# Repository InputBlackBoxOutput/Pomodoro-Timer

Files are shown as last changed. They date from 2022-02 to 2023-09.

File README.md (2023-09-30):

# Pomodoro Timer

A Pomodoro timer helps you focus on a task for 25 minutes and then take a 5-minute break

## 5 steps of the Pomodoro technique
1. Choose a task
2. Set the timer for 25 minutes
3. Work on the task until the timer rings
4. Take a 5-minute break
5. Repeat steps 1-4 three more times

## 3D Render: PCB + Enclosure
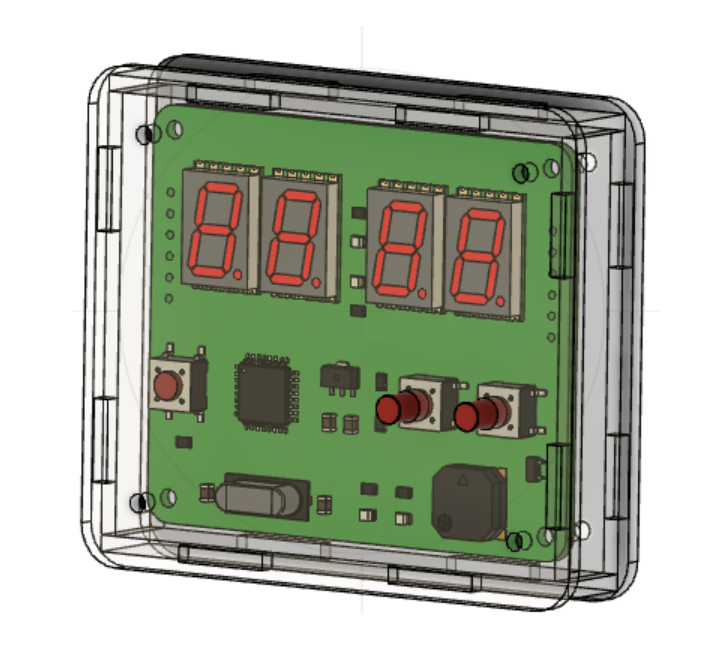
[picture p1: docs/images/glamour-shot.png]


## Hardware block diagram
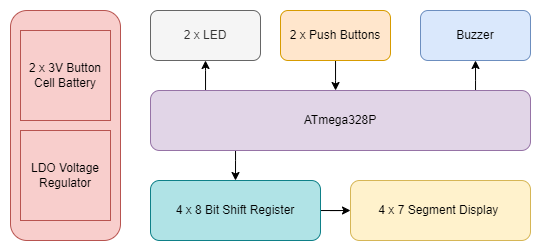
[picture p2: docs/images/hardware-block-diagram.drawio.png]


| Component | Function |
|--|--|
| ATmega328P | Micro-controller that controls all functionality |
| LED | Indicate the status of the Pomodoro timer |
| Push buttons | Provide an interface to start/stop and reset the Pomodoro timer |
| Buzzer | Provide auditory feedback upon completion of the timer |
| 4x7 segment display | Displays remaining time for the Pomodoro session |
| LDO voltage regulator | Efficiently regulates the voltage supplied to the embedded system |
| Cell battery | Provides power to the entire system |

### Made with lots of ⏱️, 📚 and ☕ by InputBlackBoxOutput

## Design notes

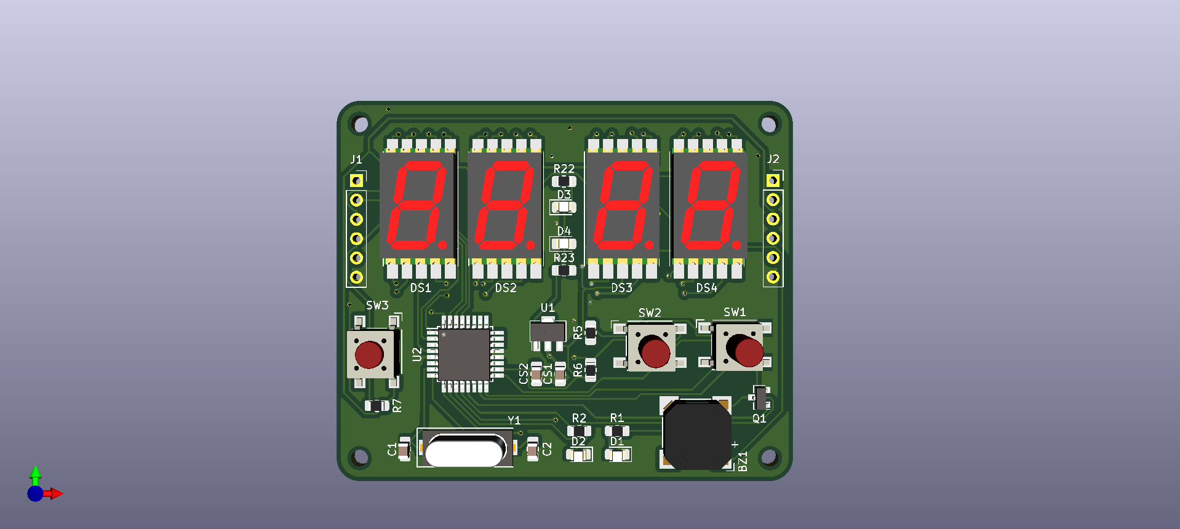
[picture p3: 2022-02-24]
docs/images/pcb-front.png

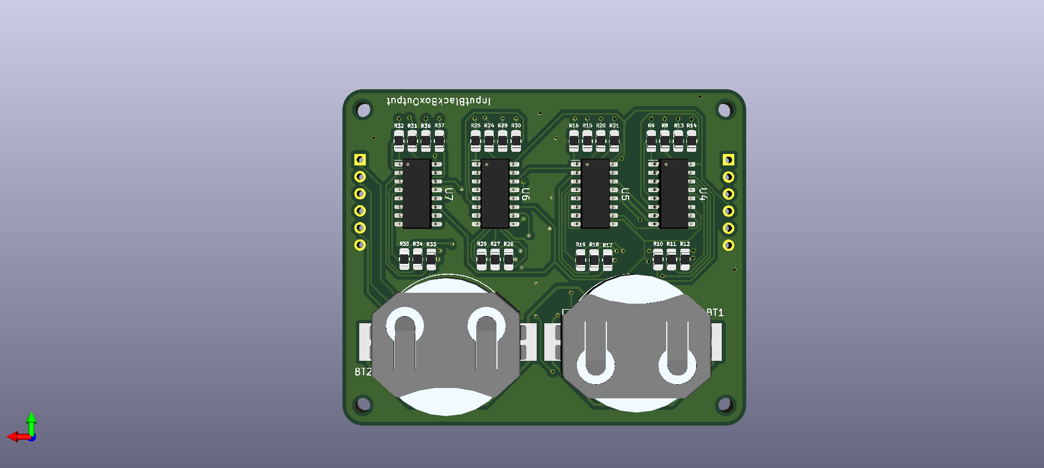
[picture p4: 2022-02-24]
docs/images/pcb-back.png

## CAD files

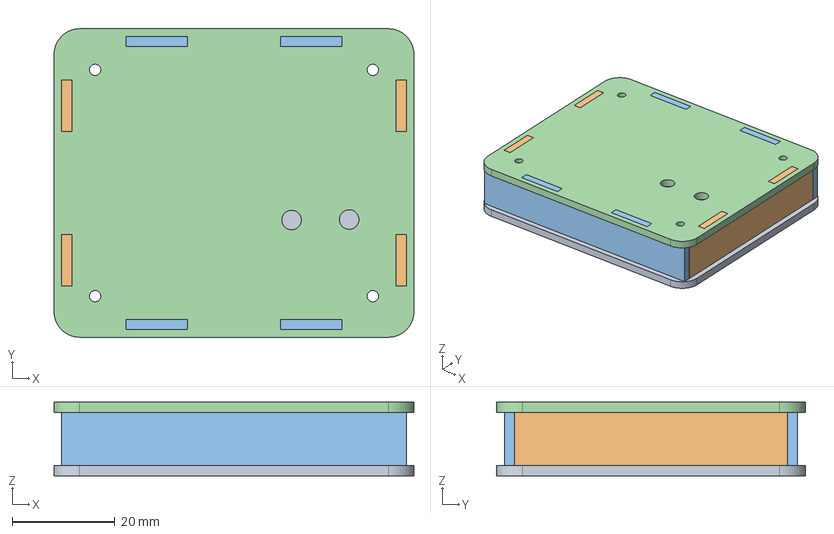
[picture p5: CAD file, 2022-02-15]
enclosure/enclosure.step
70.0 x 60.0 x 14.3 mm
Bottom
Left
Right
Front
Back
Top

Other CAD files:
enclosure/enclosure.dxf
enclosure/enclosure.f3d

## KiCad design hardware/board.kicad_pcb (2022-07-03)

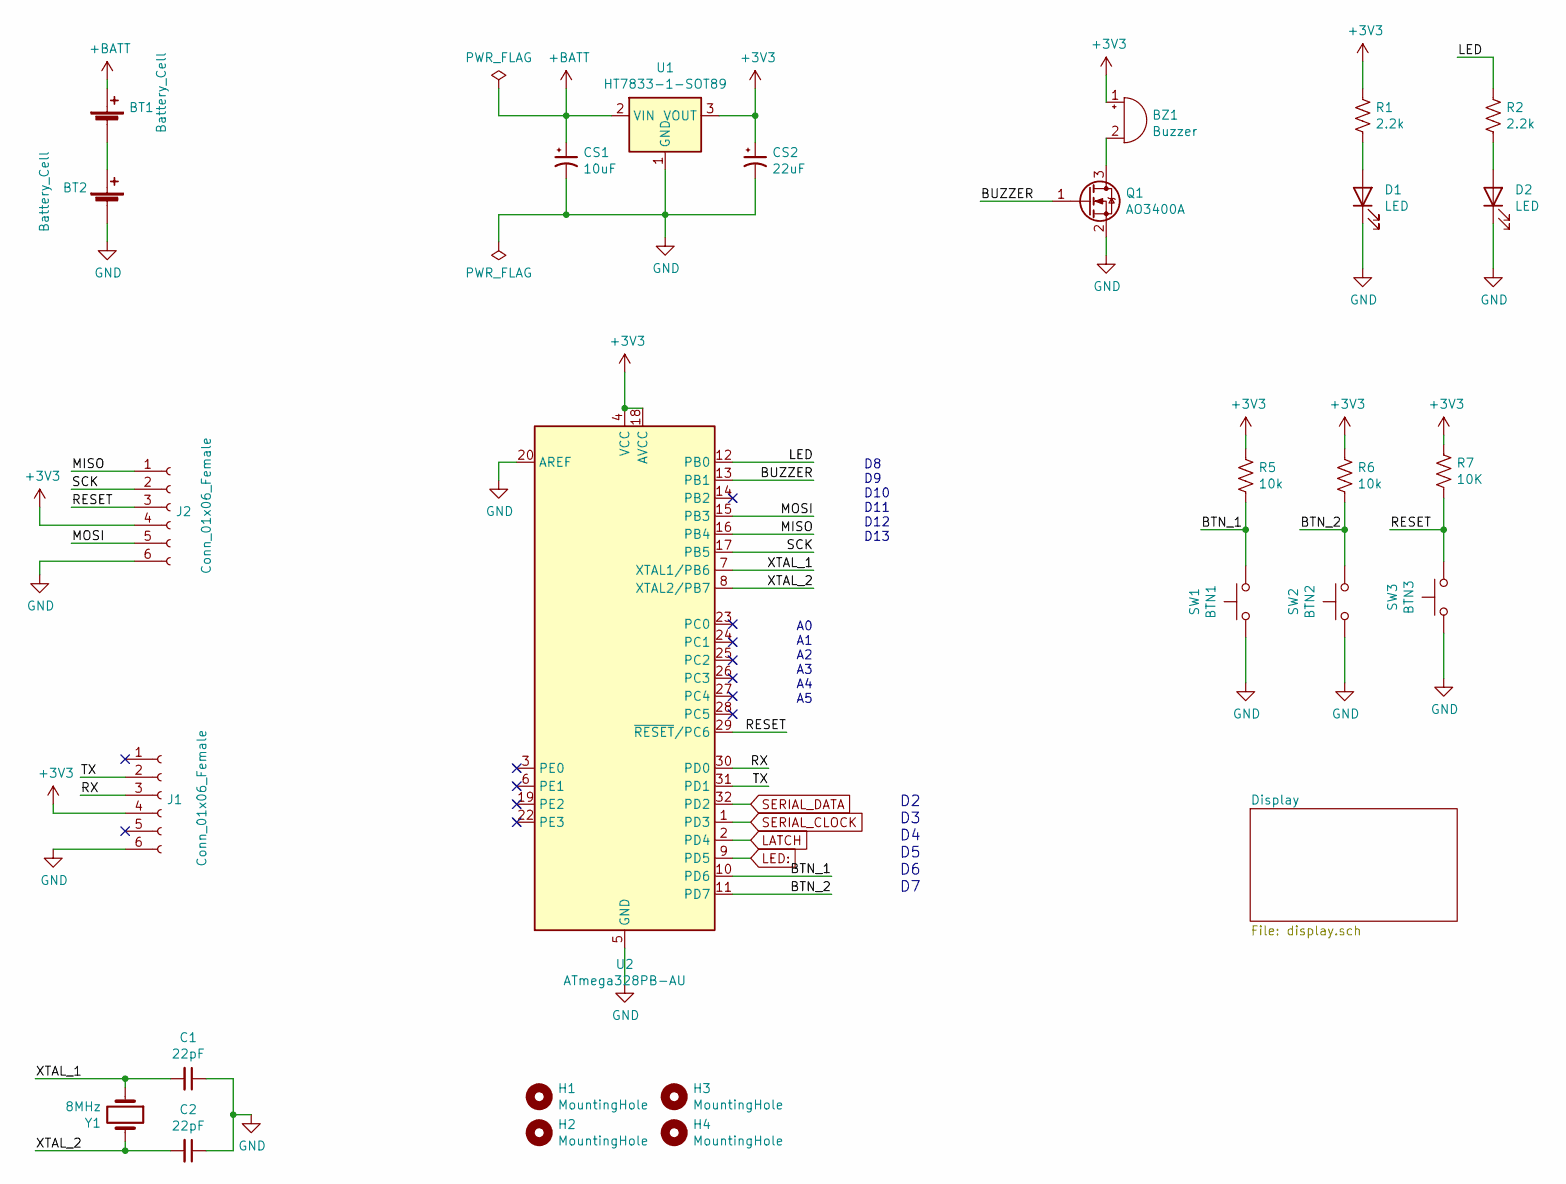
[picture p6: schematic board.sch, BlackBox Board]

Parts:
BT1, BT2: Battery_Cell; BatteryHolder_MPD_BC2003_1x2032
BZ1: Buzzer; MagneticBuzzer_CUI_CMT-8504-100-SMT
C1, C2: 22pF; C_0805_2012Metric_Pad1.18x1.45mm_HandSolder
CS1: 10uF; C_0805_2012Metric_Pad1.18x1.45mm_HandSolder
CS2: 22uF; C_0805_2012Metric_Pad1.18x1.45mm_HandSolder
D1, D2: LED; LED_0805_2012Metric_Pad1.15x1.40mm_HandSolder
H1, H2, H3, H4: MountingHole; MountingHole_2.2mm_M2
J1, J2: Conn_01x06_Female; PinSocket_1x06_P2.54mm_Vertical
Q1: AO3400A; SOT-23
R1, R2: 2.2k; R_0805_2012Metric_Pad1.20x1.40mm_HandSolder
R5, R6: 10k; R_0805_2012Metric_Pad1.20x1.40mm_HandSolder
R7: 10K; R_0805_2012Metric_Pad1.20x1.40mm_HandSolder
SW1: BTN1; SW_SPST_Omron_B3FS-100xP
SW2: BTN2; SW_SPST_Omron_B3FS-100xP
SW3: BTN3; SW_SPST_Omron_B3FS-100xP
U1: HT7833-1-SOT89; SOT-89-3
U2: ATmega328PB-AU; TQFP-32_7x7mm_P0.8mm
Y1: 8MHz; Crystal_SMD_HC49-SD

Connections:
+3V3: BZ1.1 (-), CS2.1, J1.4, J2.4, R1.1, R5.1, R6.1, R7.1, U1.3 (VOUT), U2.4 (VCC), U2.18 (AVCC); also elsewhere on the board
+BATT: BT1.1 (+), CS1.1, U1.2 (VIN)
/BTN_1: R5.2, SW1.2, U2.10 (PD6)
/BTN_2: R6.2, SW2.2, U2.11 (PD7)
/BUZZER: Q1.1 (G), U2.13 (PB1)
/LED: R2.1, U2.12 (PB0)
/MISO: J2.1, U2.16 (PB4)
/MOSI: J2.5, U2.15 (PB3)
/RESET: J2.3, R7.2, SW3.2, U2.29 (~RESET~/PC6)
/RX: J1.3, U2.30 (PD0)
/SCK: J2.2, U2.17 (PB5)
/TX: J1.2, U2.31 (PD1)
/XTAL_1: C1.2, U2.7 (XTAL1/PB6), Y1.1
/XTAL_2: C2.2, U2.8 (XTAL2/PB7), Y1.2
GND: BT2.2 (-), C1.1, C2.1, CS1.2, CS2.2, D1.1 (K), D2.1 (K), J1.6, J2.6, Q1.2 (S), SW1.1, SW2.1, SW3.1, U1.1 (GND), U2.5 (GND), U2.20 (AREF), U2.21 (GND); also elsewhere on the board
LATCH: U2.2 (PD4); also elsewhere on the board
LED:: U2.9 (PD5); also elsewhere on the board
unnamed: BT1.2 (-), BT2.1 (+)
unnamed: BZ1.2 (+), Q1.3 (D)
unnamed: D1.2 (A), R1.2
unnamed: D2.2 (A), R2.2
SERIAL_CLOCK: U2.1 (PD3); also elsewhere on the board
SERIAL_DATA: U2.32 (PD2); also elsewhere on the board

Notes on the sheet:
D2 D3 D4 D5 D6 D7
D8 D9 D10 D11 D12 D13
A0 A1 A2 A3 A4 A5

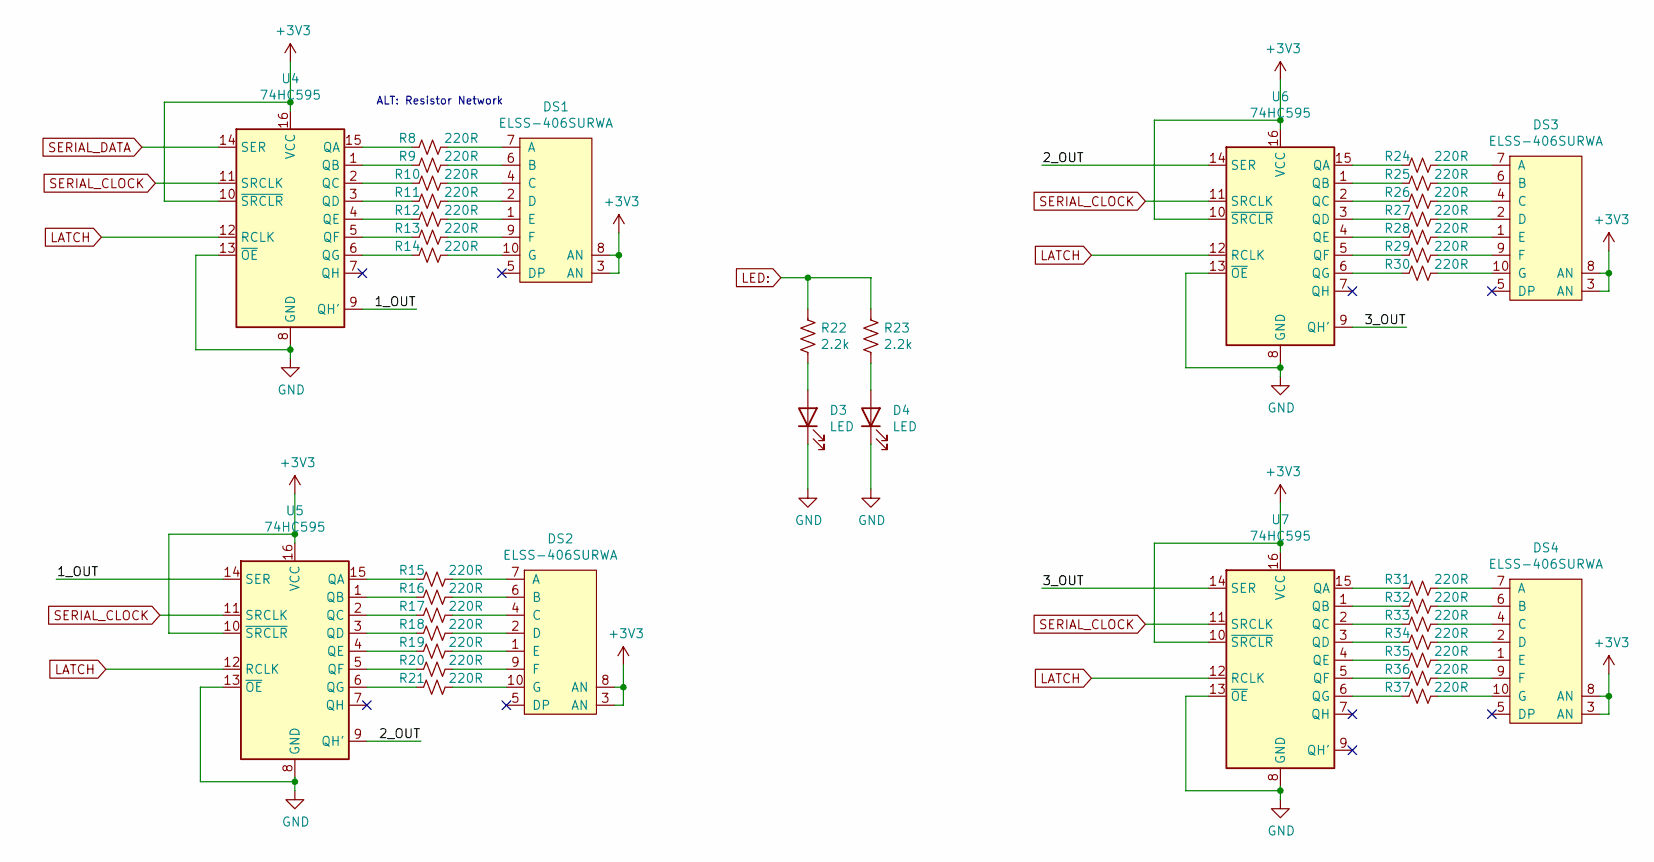
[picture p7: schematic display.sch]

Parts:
D3, D4: LED; LED_0805_2012Metric_Pad1.15x1.40mm_HandSolder
DS1, DS2, DS3, DS4: ELSS-406SURWA
R8, R9, R10, R11, R12, R13, R14, R15, R16, R17, R18, R19, R20, R21, R24, R25, R26, R27, R28, R29, R30, R31, R32, R33, R34, R35, R36, R37: 220R; R_0805_2012Metric_Pad1.20x1.40mm_HandSolder
R22, R23: 2.2k; R_0805_2012Metric_Pad1.20x1.40mm_HandSolder
U4, U5, U6, U7: 74HC595; SOP-16_3.9x9.9mm_P1.27mm

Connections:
+3V3: DS1.3 (AN), DS1.8 (AN), DS2.3 (AN), DS2.8 (AN), DS3.3 (AN), DS3.8 (AN), DS4.3 (AN), DS4.8 (AN), U4.10 (~SRCLR), U4.16 (VCC), U5.10 (~SRCLR), U5.16 (VCC), U6.10 (~SRCLR), U6.16 (VCC), U7.10 (~SRCLR), U7.16 (VCC); also elsewhere on the board
/Display/1_OUT: U4.9 (QH'), U5.14 (SER)
/Display/2_OUT: U5.9 (QH'), U6.14 (SER)
/Display/3_OUT: U6.9 (QH'), U7.14 (SER)
GND: D3.1 (K), D4.1 (K), U4.8 (GND), U4.13 (~OE), U5.8 (GND), U5.13 (~OE), U6.8 (GND), U6.13 (~OE), U7.8 (GND), U7.13 (~OE); also elsewhere on the board
LATCH: U4.12 (RCLK), U5.12 (RCLK), U6.12 (RCLK), U7.12 (RCLK); also elsewhere on the board
LED:: R22.1, R23.1; also elsewhere on the board
unnamed: D3.2 (A), R22.2
unnamed: D4.2 (A), R23.2
unnamed: DS1.1 (E), R12.1
unnamed: DS1.2 (D), R11.1
unnamed: DS1.4 (C), R10.1
unnamed: DS1.6 (B), R9.1
unnamed: DS1.7 (A), R8.1
unnamed: DS1.9 (F), R13.1
unnamed: DS1.10 (G), R14.1
unnamed: DS2.1 (E), R19.1
unnamed: DS2.2 (D), R18.1
unnamed: DS2.4 (C), R17.1
unnamed: DS2.6 (B), R16.1
unnamed: DS2.7 (A), R15.1
unnamed: DS2.9 (F), R20.1
unnamed: DS2.10 (G), R21.1
unnamed: DS3.1 (E), R28.1
unnamed: DS3.2 (D), R27.1
unnamed: DS3.4 (C), R26.1
unnamed: DS3.6 (B), R25.1
unnamed: DS3.7 (A), R24.1
unnamed: DS3.9 (F), R29.1
unnamed: DS3.10 (G), R30.1
unnamed: DS4.1 (E), R35.1
unnamed: DS4.2 (D), R34.1
unnamed: DS4.4 (C), R33.1
unnamed: DS4.6 (B), R32.1
unnamed: DS4.7 (A), R31.1
unnamed: DS4.9 (F), R36.1
unnamed: DS4.10 (G), R37.1
unnamed: R8.2, U4.15 (QA)
unnamed: R9.2, U4.1 (QB)
unnamed: R10.2, U4.2 (QC)
unnamed: R11.2, U4.3 (QD)
unnamed: R12.2, U4.4 (QE)
unnamed: R13.2, U4.5 (QF)
unnamed: R14.2, U4.6 (QG)
unnamed: R15.2, U5.15 (QA)
unnamed: R16.2, U5.1 (QB)
unnamed: R17.2, U5.2 (QC)
unnamed: R18.2, U5.3 (QD)
unnamed: R19.2, U5.4 (QE)
unnamed: R20.2, U5.5 (QF)
unnamed: R21.2, U5.6 (QG)
unnamed: R24.2, U6.15 (QA)
unnamed: R25.2, U6.1 (QB)
unnamed: R26.2, U6.2 (QC)
unnamed: R27.2, U6.3 (QD)
unnamed: R28.2, U6.4 (QE)
unnamed: R29.2, U6.5 (QF)
unnamed: R30.2, U6.6 (QG)
unnamed: R31.2, U7.15 (QA)
unnamed: R32.2, U7.1 (QB)
unnamed: R33.2, U7.2 (QC)
unnamed: R34.2, U7.3 (QD)
unnamed: R35.2, U7.4 (QE)
unnamed: R36.2, U7.5 (QF)
unnamed: R37.2, U7.6 (QG)
SERIAL_CLOCK: U4.11 (SRCLK), U5.11 (SRCLK), U6.11 (SRCLK), U7.11 (SRCLK); also elsewhere on the board
SERIAL_DATA: U4.14 (SER); also elsewhere on the board

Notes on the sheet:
ALT: Resistor Network

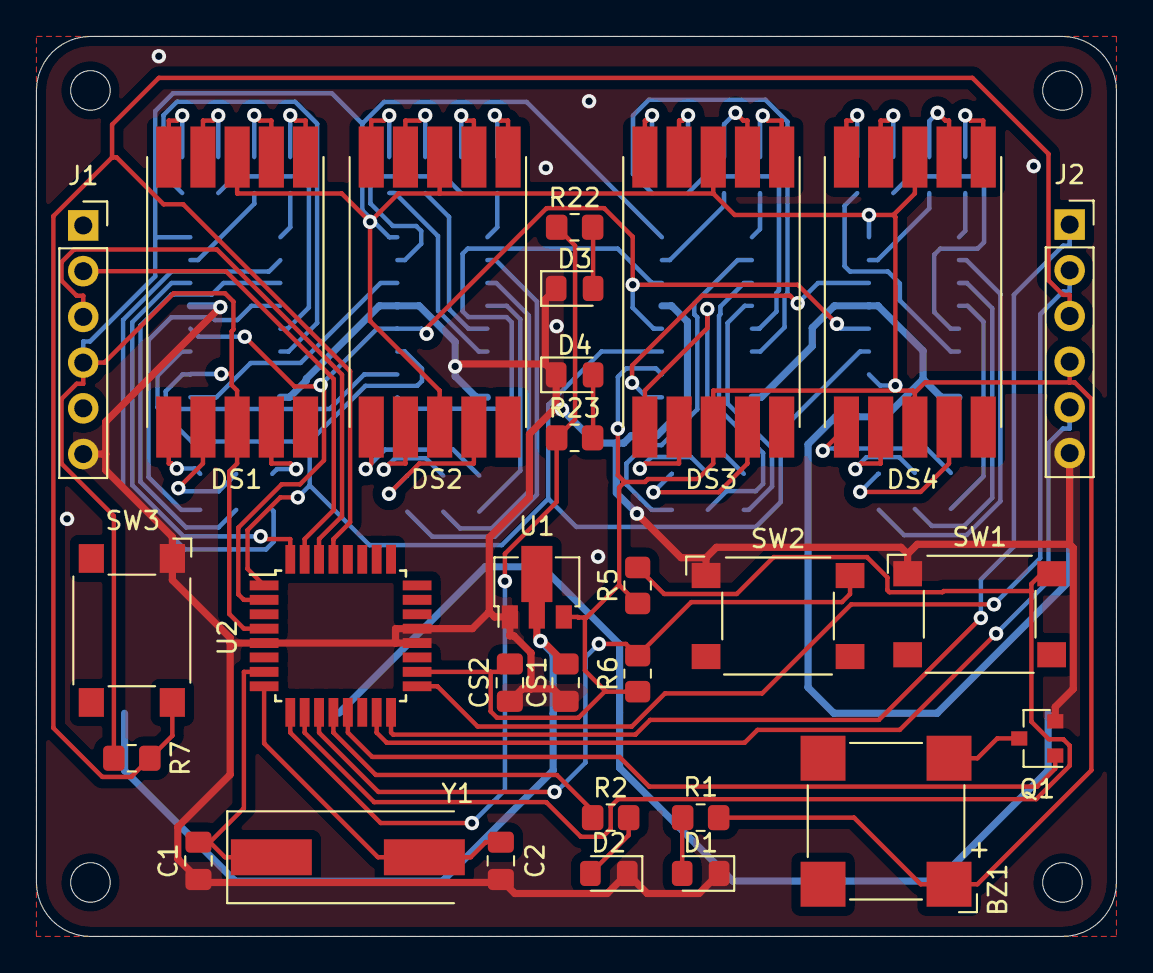
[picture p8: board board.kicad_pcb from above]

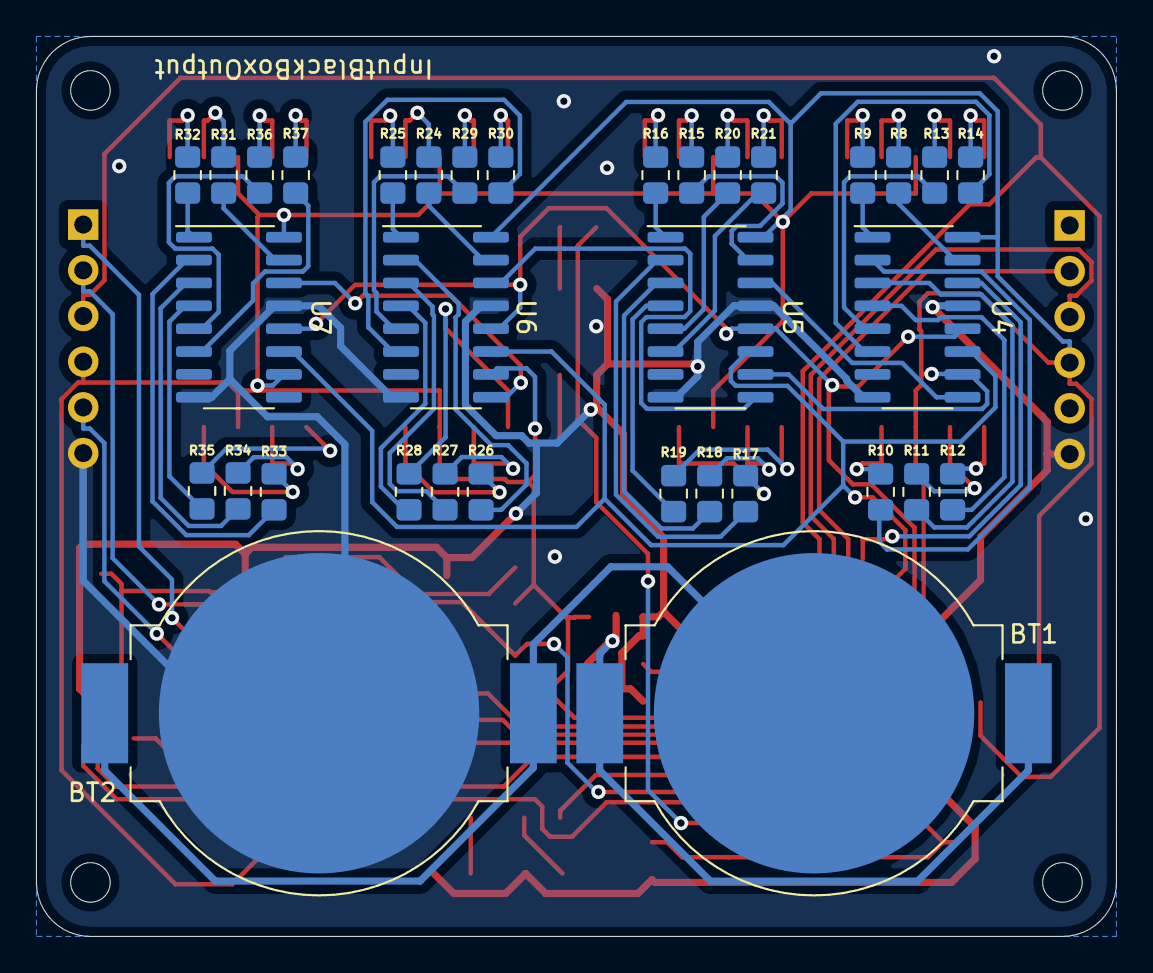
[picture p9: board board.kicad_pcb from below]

Board: 2 copper layers, 60.0 x 50.0 mm, 67 parts (34 on the bottom side), 84 nets.

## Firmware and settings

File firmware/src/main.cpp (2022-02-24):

#include <Arduino.h>
#include "connections.h"

unsigned long start_time = 0;
unsigned long now = 0;
bool timer_on = false;

const uint8_t mapping[10] = {
  /*0*/ 0b11111100,
  /*1*/ 0b01100000,
  /*2*/ 0b11011010,
  /*3*/ 0b11110010,
  /*4*/ 0b01100110,
  /*5*/ 0b10110110,
  /*6*/ 0b10111110,
  /*7*/ 0b11100000,
  /*8*/ 0b11111110,
  /*9*/ 0b11110110,
};


void blinkLED(uint8_t times) {
  for(int i=0; i<times; i++) {
    digitalWrite(LED, HIGH);
    delay(100);
    digitalWrite(LED, LOW);
    delay(100);
  }
}

void soundBuzzer(uint8_t times) {
  for(int i=0; i<times; i++) {
    tone(BUZZER, 1000);
    delay(100);    
    noTone(BUZZER);  
    delay(100);
  }
}


int* convertToMinutesSeconds(unsigned long t) {
  static int n[4] = {0, 0, 0, 0};

  t = t / 1000;
  long minutes = t / 60;
  long seconds = t % 60;

  n[1] = (int) (minutes%10);
  if (minutes > 9) {
    n[0] = minutes/10;
  }

  n[3] = (int) (seconds%10);
  if (seconds > 9) {
    n[2] = seconds/10;
  }

  return n;
}

void clearDisplay() {
  digitalWrite(LATCH, LOW);
  for(uint8_t i=0; i<4; i++) {
   shiftOut(SERIAL_DATA, SERIAL_CLK, LSBFIRST, 0);
  }
  digitalWrite(LATCH, HIGH);
}

void writeDigitsOnDisplay(int* n) {
  digitalWrite(LATCH, LOW);
  for(uint8_t i=0; i<4; i++) {
   shiftOut(SERIAL_DATA, SERIAL_CLK, LSBFIRST, mapping[*(n+i)]);
  }
  digitalWrite(LATCH, HIGH);
}

void setup() {
  Serial.begin(115200);

  pinMode(LED, OUTPUT);
  pinMode(BUZZER, OUTPUT);
  
  pinMode(BTN1, INPUT);
  pinMode(BTN2, INPUT);

  pinMode(SERIAL_DATA, OUTPUT);
  pinMode(SERIAL_CLK, OUTPUT);
  pinMode(LATCH, OUTPUT);

  pinMode(LED_COLON, OUTPUT);
  digitalWrite(LED_COLON, HIGH);

  clearDisplay();
}

void loop() {
  if(digitalRead(BTN1)) {
    soundBuzzer(1);
    blinkLED(1);
    timer_on = true;
    start_time = 0;
  }
  if(digitalRead(BTN2)) {
    soundBuzzer(1);
    blinkLED(1);
    timer_on = false;
    clearDisplay();
  }

  
  if(timer_on) {
    now = millis();

    if(now - start_time == 1500000L) { // 25 minutes
      soundBuzzer(1);
      blinkLED(1);
    }
    if(now - start_time == 1800000L) { // 30 minutes
      soundBuzzer(2);
      blinkLED(2);
    }

    writeDigitsOnDisplay(convertToMinutesSeconds(now));
  }

  delayMicroseconds(100);
}

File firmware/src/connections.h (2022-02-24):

#ifndef CONNECTIONS_H
#define CONNECTIONS_H

    #define LED           8
    #define BUZZER        9
    
    #define BTN1          6
    #define BTN2          7
    
    #define SERIAL_DATA   2
    #define SERIAL_CLK    3
    #define LATCH         4
    #define LED_COLON     5

#endif

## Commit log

2022-02-15 Hardware added
    [board.dsn, board.kicad_pcb, board.sch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]
2022-02-15 Enclosure added
    [enclosure.dxf, enclosure.f3d, enclosure.step]
2022-07-03 Folder reorganized: hardware
    [board.kicad_pcb, board.sch]
